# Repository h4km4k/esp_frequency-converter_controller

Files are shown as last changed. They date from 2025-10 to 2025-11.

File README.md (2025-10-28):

# esp_frequency-converter_controller
This is a repository to control a frequency converter (with 0-10V) via web interface.

The ESP8266 and ESP32-Websocket version is not latest, please do it by yourself if you need it (and if you did it, make a PR, thank you :)).

### CONTRIBUTIONS: 
#### #Thanks to Ole for designing and printing the 3D parts used in this project. Your contribution made the hardware setup possible!
#### #Many thanks also to Murph as the initiator.

## Parts used:
~~YB-ESP32-S3-ETH DevBoard with Ethernet+WiFi, 4MB Flash, 2xUSB, Antenna https://ebay.us/m/mVzUvF~~

1x WT32-ETH01 ESP32 WROOM LAN8720 Ethernet Arduino ESPEasy Tasmota Entwicklerboard https://ebay.us/m/NcotwB

1x PWM-Drehspannungsmodul, 0 % - 100 % PWM-Drehung auf 0 V-10 V Spannung https://ebay.us/m/Sh1sWy

2x 1-Kanal 3.3V Relais Modul mit Optokoppler (1Ch Relay Module High/Low Trigger) https://ebay.us/m/U08Ens

1x CH340G USB UART TTL Adapter 3,3V/5V für Arduino ESP8266 ESP32 Serial Converter https://ebay.us/m/q4AG8j

## The Circuit:

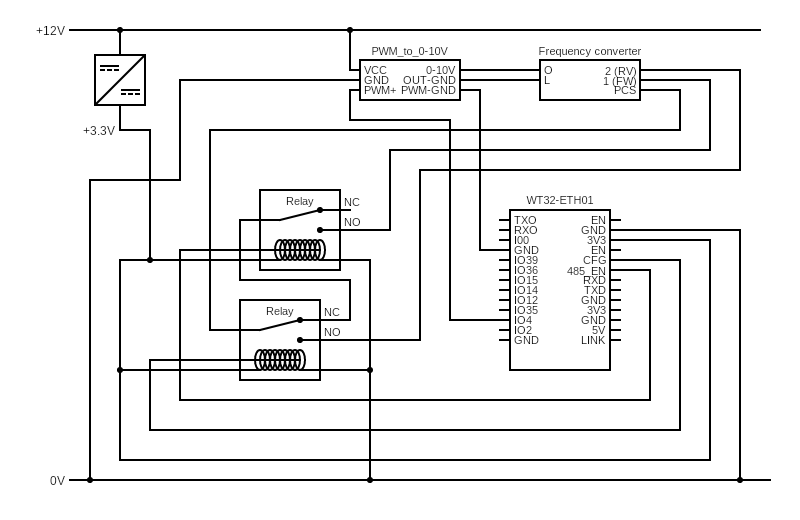
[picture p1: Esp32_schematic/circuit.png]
Circuit


## Favicon
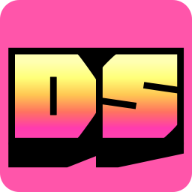
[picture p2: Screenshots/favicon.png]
Favicon


## Screenshots
<p align="left">
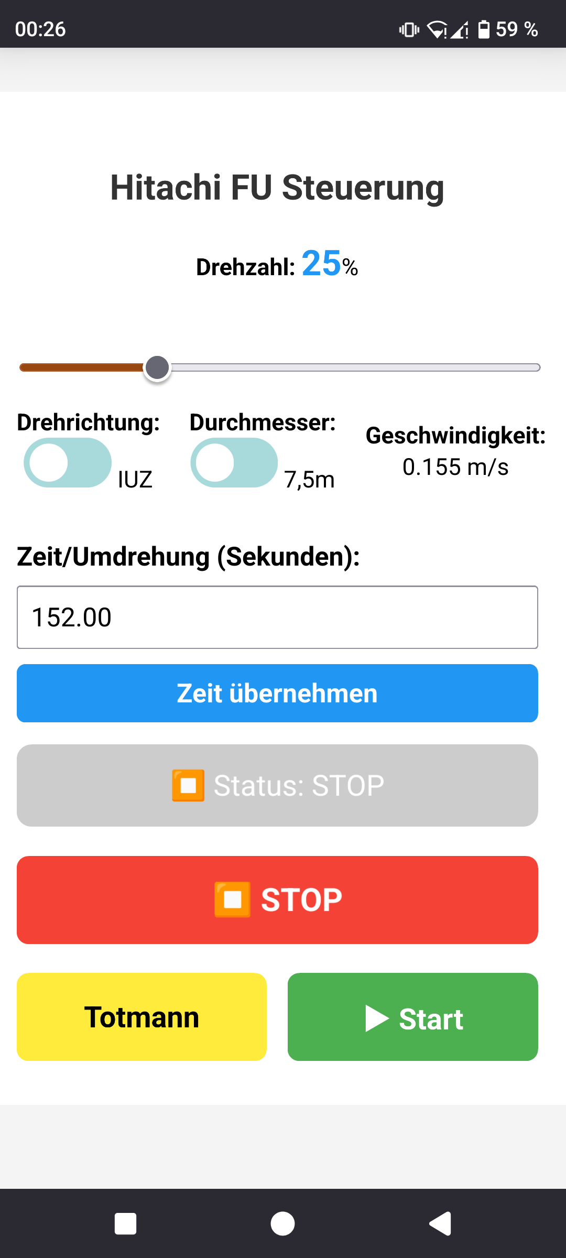
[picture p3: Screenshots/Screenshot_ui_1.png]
First Screenshot
  
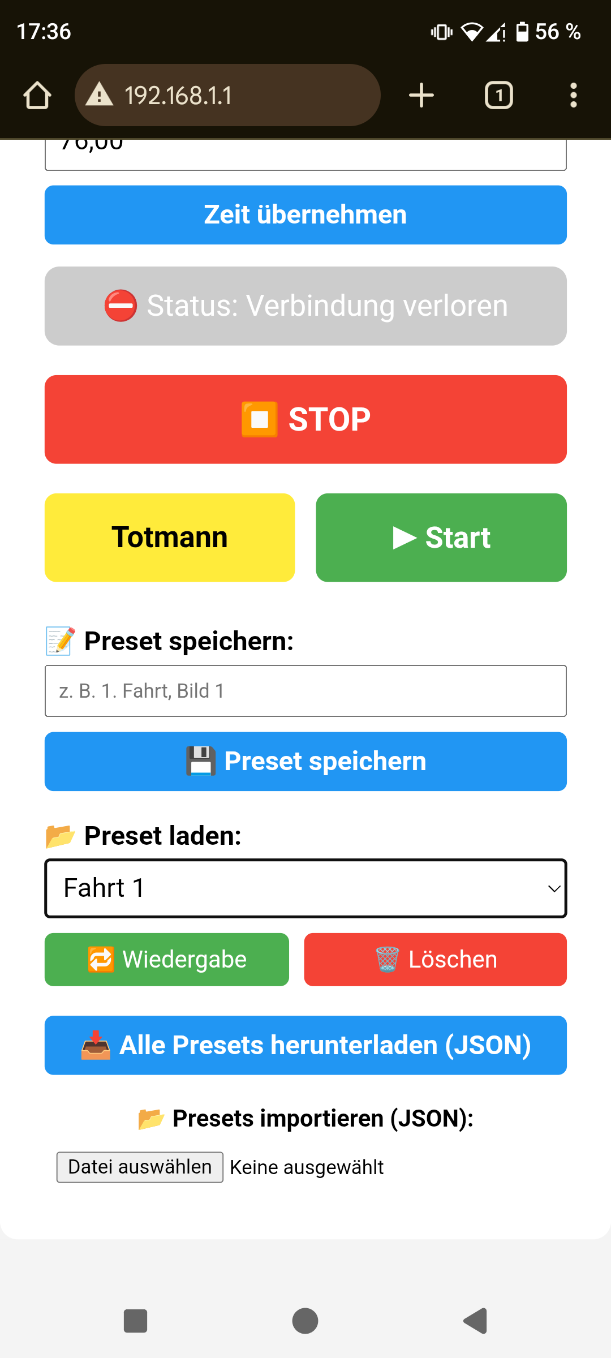
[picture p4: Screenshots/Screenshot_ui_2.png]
Second Screenshot
  
</p>

## 3D-Models
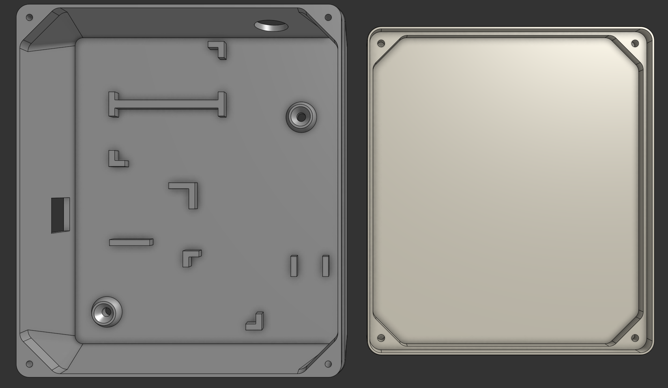
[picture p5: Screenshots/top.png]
Solid Top


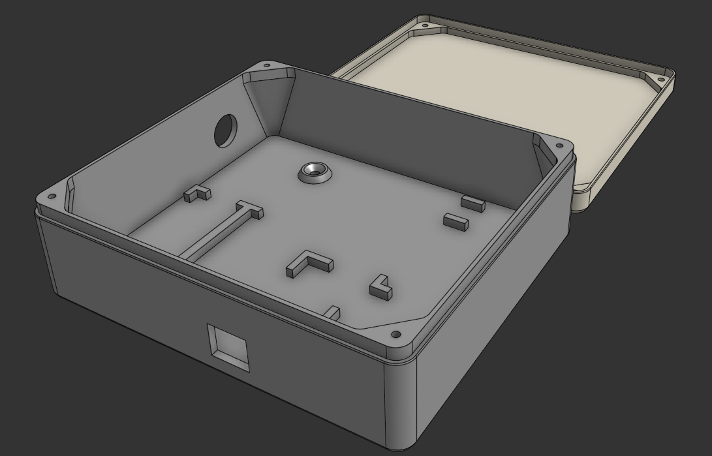
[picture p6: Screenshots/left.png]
Solid Left


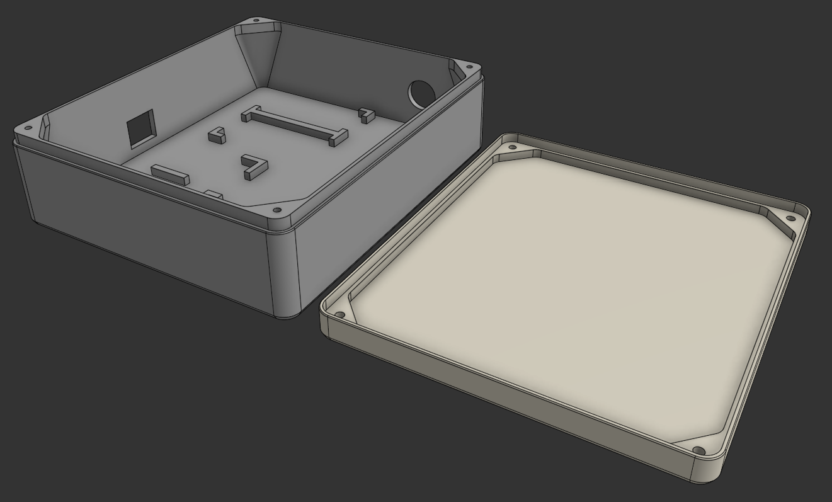
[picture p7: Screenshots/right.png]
Solid Right


## Assembled 

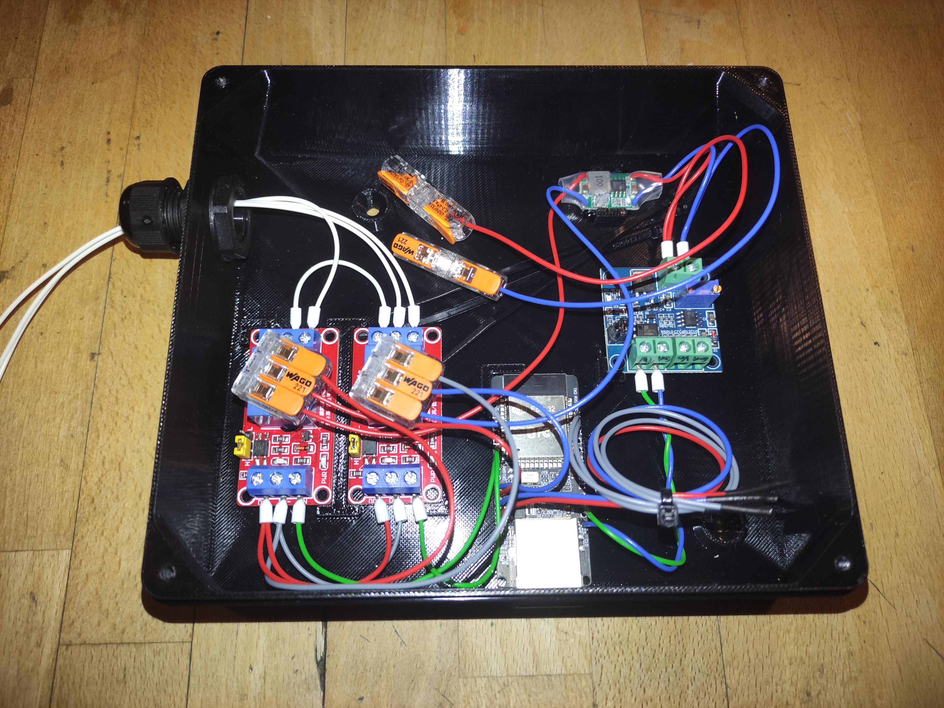
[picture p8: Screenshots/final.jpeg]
Assembly


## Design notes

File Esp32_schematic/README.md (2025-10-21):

To edit the schematic go to: <https://www.circuit-diagram.org/editor/> and load the *.cddx file into the editor.

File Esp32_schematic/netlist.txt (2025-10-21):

* Netlist created with www.circuit-diagram.org
* 
V1 0 3.3
'dcdcconverter primary:1 secondary:0 primary=DC secondary=DC
V2 2 0
'microcontroller #5:3 #1:4 #3:5 #0:6 #2:7 header=Frequency converter sz=6 p0=O p1=2 (RV) p2=L p3=1 (FW) p4= p5=PCS p6= p7= p8= p9= p10= p11= p12= p13= p14= p15= p16= p17= p18= p19= p20= p21= p22= p23= p24= p25= p26= p27= p28= p29= p30= p31= p32= p33= p34= p35= p36= p37= p38= p39=
'microcontroller #5:8 #1:6 #3:7 #2:2 #0:1 #4:9 header=PWM_to_0-10V sz=6 p0=VCC p1=0-10V p2=GND p3=OUT-GND p4=PWM+ p5=PWM-GND p6= p7= p8= p9= p10= p11= p12= p13= p14= p15= p16= p17= p18= p19= p20= p21= p22= p23= p24= p25= p26= p27= p28= p29= p30= p31= p32= p33= p34= p35= p36= p37= p38= p39=
'microcontroller #3:2 #5:0 #6:8 #20:9 #9:10 #11:11 header=WT32-ETH01 sz=30 p0=TXO p1=EN p2=RXO p3=GND p4=I00 p5=3V3 p6=GND p7=EN p8=IO39 p9=CFG p10=IO36 p11=485_EN p12=IO15 p13=RXD p14=IO14 p15=TXD p16=IO12 p17=GND p18=IO35 p19=3V3 p20=IO4 p21=GND p22=IO2 p23=5V p24=GND p25=LINK p26= p27= p28= p29= p30= p31= p32= p33= p34= p35= p36= p37= p38= p39=
'Relay 3:3 5:4 4:12 2:2 1:0
'Relay 5:5 3:12 4:13 2:2 1:0
V3 1 12

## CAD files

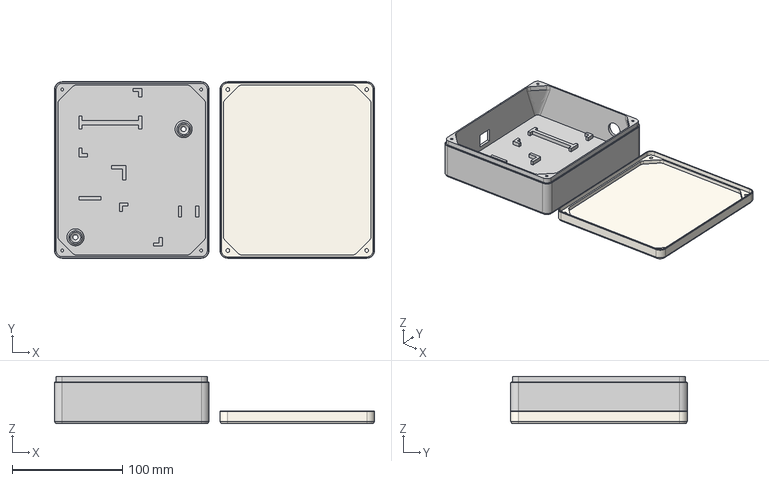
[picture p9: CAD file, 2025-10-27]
3d-files/DrehS_Frequenz_Gehause.step
290.0 x 160.0 x 43.0 mm

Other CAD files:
3d-files/DrehS_Frequenz_Gehause.stl

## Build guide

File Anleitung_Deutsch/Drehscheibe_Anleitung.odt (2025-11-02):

### Quickstart:

1. Vorbereitung:
Schalten Sie zunächst die mobilen Daten Ihres Endgeräts aus.

2. Verbindung herstellen:
Scannen Sie anschließend den WLAN-QR-Code.
Sobald die Verbindung mit „ESP-FU-Steuerung“ hergestellt ist, scannen Sie den LINK-QR-Code, um das User-Interface zu öffnen.

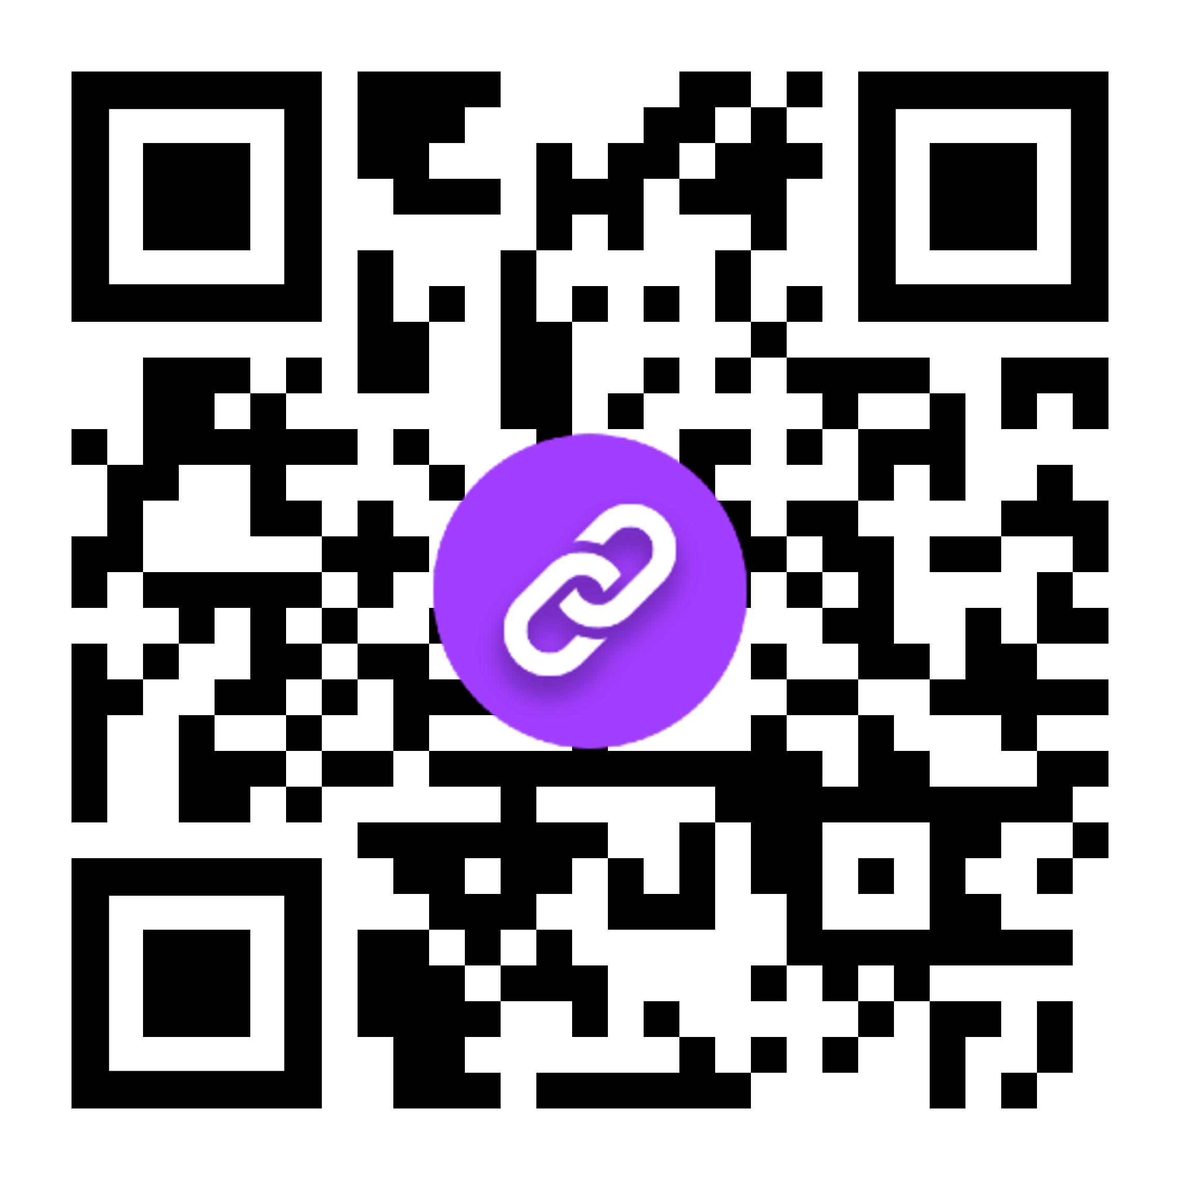
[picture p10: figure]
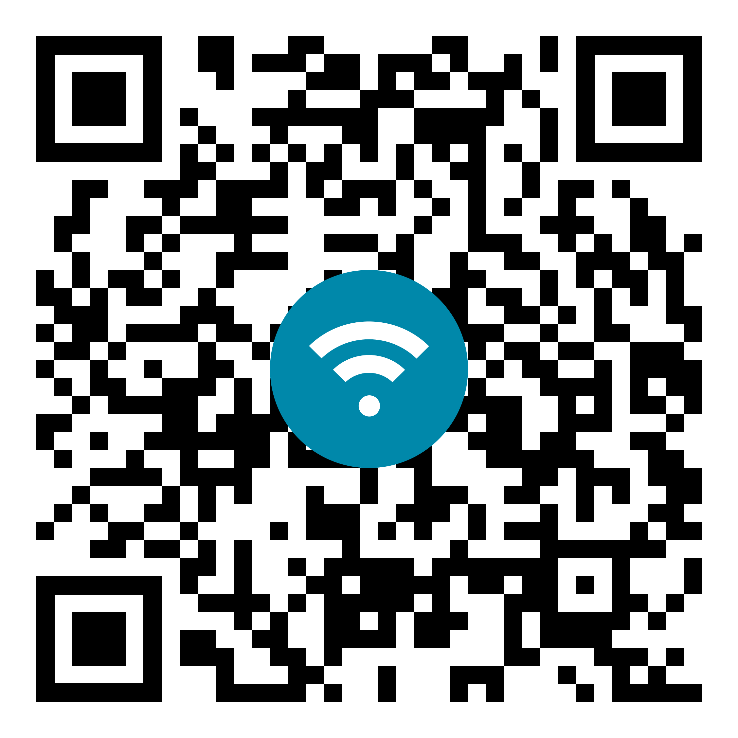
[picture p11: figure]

3. Bedienung:

1. Wählen Sie die gewünschte Drehrichtung und Geschwindigkeit (über den Slider oder per Zeiteingabe).

2. Drücken und halten Sie die „Totmensch“-Taste.

3. Zum Starten: Start-Taste drücken.

4. Zum Stoppen: Stop-Taste drücken.

Tipps&Tricks:

- Für vollen Funktionsumfang den Chrome Browser nutzen.

### Niemals Start oder Wiedergabe drücken ohne Totmensch.

### Wenn Etwas komisch ist in die Browser Adressleiste gehen und Seite neu laden.

## Erweiterte Funktionen

### LAN oder WLAN

LAN-Modus:
Wenn Sie das Gerät im LAN-Only-Modus betreiben möchten, schließen Sie Ihr eingeschaltetes Endgerät an den RJ45-Port an. Schalten Sie anschließend den Hauptschalter des Schaltschrankes ein.

WLAN-Modus:
Wird kein eingeschaltetes Gerät am LAN-Port erkannt, startet die Steuerung automatisch einen WLAN-Zugangspunkt.

Tipps & Tricks:

- Modus kann nur durch stromlos schalten geändert werden.

### Presets

Fahrt speichern:
Um eine gerade durchgeführte Fahrt zu speichern – inklusive aller Geschwindigkeitsänderungen (über Slider anpassen) und erneutes Starten – geben Sie einen Namen ein und drücken Sie auf „Preset speichern“.

Einschränkung:
Eine Fahrt, die durch Loslassen des „Totmensch“-Buttons beendet wurde, gilt nicht als gültige Fahrt und kann daher nicht gespeichert werden.

Tipps & Tricks:

- Presets funktionieren nur richtig, wenn der Motor keinen Schlupf hat.
- Presets wurden getestet, befinden sich aber noch in der BETA-Phase.
- Der Totmensch muss auch bei der Wiedergabe gehalten werden.

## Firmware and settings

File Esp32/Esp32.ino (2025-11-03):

#include <ETH.h>
#include <WiFi.h>
#include <WebServer.h>
#include <ArduinoOTA.h>
#include "DhcpServerLAN.h"
#include "esp_wifi.h"
#include "webinterface.h"
#include "favicon.h"
#include "manifest.h"

DhcpServerLAN dhcp;

WebServer server(80);

const char sw_js[] PROGMEM = R"(
self.addEventListener('install', (e) => {
  self.skipWaiting();
});
self.addEventListener('fetch', (e) => {
  e.respondWith(fetch(e.request));
});
)";

const char* ssid = "ESP-FU-Steuerung";
const char* password = "esp12345";

String currentDirection = "IUZ";
int dutyCycle = 0;
int currentPwm = 0;
int currentDuty = 0;
int targetPwm = 0;
bool startFreigegeben = false;
bool lanActive = false;
unsigned long lastTotmannSignal = 0;
const unsigned long totmannTimeout = 1000;

float scheibenDurchmesser = 7.5;



const int pwmPin = 4;
const int pwmFreq = 2900;
const int pwmResolution = 10;  // 10 Bit Auflösung (0-1023)
const int pwmRange = 1023;
const int minPWM = 80;  // Mindestwert, bei dem dein Motor zuverlässig anläuft (kannst du anpassen)

const int relay1Pin = 32;
const int relay2Pin = 33;


const int n = 11;
float fahrzeit[] = { 38.28, 38.25, 44.73, 51.84, 61.45, 73.56, 94.41, 126.24, 184.87, 531.15, 2000 };
int pwmProzent[] = { 100, 90, 80, 70, 60, 50, 40, 30, 20, 10, 1 };

unsigned long lastRampUpdate = 0;
const unsigned long rampStepDelay = 4;



int getPWMForFahrzeit(float zeit) {
  if (zeit <= fahrzeit[0]) return pwmProzent[0];
  if (zeit >= fahrzeit[n - 1]) return pwmProzent[n - 1];

  for (int i = 0; i < n - 1; i++) {
    if (zeit >= fahrzeit[i] && zeit <= fahrzeit[i + 1]) {
      float t1 = fahrzeit[i];
      float t2 = fahrzeit[i + 1];
      int p1 = pwmProzent[i];
      int p2 = pwmProzent[i + 1];

      float ratio = (zeit - t1) / (t2 - t1);
      int pwm = p1 + ratio * (p2 - p1);

      return pwm;
    }
  }
  return pwmProzent[n - 1];
}

void handleSet() {
  if (server.hasArg("duty")) {
    int val = server.arg("duty").toInt();
    if (val >= 0 && val <= 100) {
      if (val <= 0) {
        dutyCycle = 0;
      } else {
        dutyCycle = minPWM + (int)((val - 1) / 99.0 * (1023 - minPWM));
      }
      currentDuty = val;
      server.send(200, "text/plain", "OK");
      return;
    }
  }
  server.send(400, "text/plain", "Bad Request");
}

void handleTotmann() {
  lastTotmannSignal = millis();
  server.send(200, "text/plain", "Totmann OK");
}

void handleStart() {

  bool recentTotmann = (millis() - lastTotmannSignal) < totmannTimeout;

  if (!recentTotmann) {
    server.send(400, "text/plain", "Start verweigert: Totmensch nicht aktiv");
    return;
  }

  if (dutyCycle <= 0) {
    server.send(400, "text/plain", "Start verweigert: dutyCycle=0");
    return;
  }

  startFreigegeben = true;
  targetPwm = dutyCycle;
  server.send(200, "text/plain", "Start OK");
}

void handleStop() {
  targetPwm = 0;
  startFreigegeben = false;
  server.send(200, "text/plain", "Stop OK");
}


void handleStatus() {
  bool recentTotmann = (millis() - lastTotmannSignal) < totmannTimeout;

  String status;
  if (recentTotmann && startFreigegeben) {
    status = "aktiv";
  } else if (recentTotmann && !startFreigegeben) {
    status = "warte";
  } else {
    status = "stop";
  }

  String dir = currentDirection;
  int duty = currentDuty;
  String json = "{\"status\":\"" + status + "\",\"direction\":\"" + dir + "\",\"duty\":" + String(duty) + "}";

  server.send(200, "application/json", json);
}


void handleGetDuty() {
  int dutyPercent = map(dutyCycle, 0, pwmRange, 0, 100);
  server.send(200, "text/plain", String(dutyPercent));
}

void handleGetPwm() {
  if (server.hasArg("time")) {
    float zeit = server.arg("time").toFloat();
    int pwm = getPWMForFahrzeit(zeit);
    server.send(200, "text/plain", String(pwm));
  } else {
    server.send(400, "text/plain", "Missing 'time' parameter");
  }
}

void handleSetDiameter() {
  if (server.hasArg("d")) {
    String val = server.arg("d");
    if (val == "7.5" || val == "8.5") {
      scheibenDurchmesser = val.toFloat();
      server.send(200, "text/plain", "OK");
      return;
    }
  }
  server.send(400, "text/plain", "Bad Request");
}


void setRichtungStop() {
  digitalWrite(relay1Pin, LOW);
  digitalWrite(relay2Pin, LOW);
}


void handleRichtung() {
  if (server.hasArg("dir")) {
    String dir = server.arg("dir");

    if (dir == "stop") {
      digitalWrite(relay1Pin, LOW);
      digitalWrite(relay2Pin, LOW);
      currentDirection = "STOP";
      server.send(200, "text/plain", "Richtung: STOP");
      return;
    }

    if (dir == "iuz") {
      digitalWrite(relay1Pin, HIGH);
      digitalWrite(relay2Pin, LOW);
      currentDirection = "IUZ";
      server.send(200, "text/plain", "Richtung: Im Uhrzeigersinn");
      return;
    }

    if (dir == "guz") {
      digitalWrite(relay1Pin, LOW);
      digitalWrite(relay2Pin, HIGH);
      currentDirection = "GUZ";
      server.send(200, "text/plain", "Richtung: Gegen Uhrzeigersinn");
      return;
    }

    // Falscher Parameterwert
    server.send(400, "text/plain", "Ungueltiger Wert fuer 'dir'");
    return;
  }

  // 'dir' fehlt komplett
  server.send(400, "text/plain", "Fehlender Parameter 'dir'");
}



//////////////////////////////////SETUP/////////////////////////////////////
void setup() {
  // Serial.begin(115200);

  IPAddress LanIP(192, 168, 0, 1);
  IPAddress WlanIP(192, 168, 1, 1);
  IPAddress subnet(255, 255, 255, 0);


  ETH.begin();
  ETH.config(LanIP, LanIP, subnet);
  delay(10000);

  if (ETH.linkUp()) {

    // Serial.print("LAN IP: ");
    // Serial.println(LanIP);

    lanActive = true;

    dhcp.begin(LanIP);
    dhcp.setPoolRange(200, 254);
    dhcp.setLeaseTime(3600);

    WiFi.mode(WIFI_OFF);
  } else {
    ETH.end();
    WiFi.mode(WIFI_AP);
    WiFi.softAPConfig(WlanIP, WlanIP, subnet);

    wifi_country_t myCountry = {
      .cc = "DE",
      .schan = 1,
      .nchan = 13,
      .policy = WIFI_COUNTRY_POLICY_MANUAL
    };
    esp_wifi_set_country(&myCountry);
    esp_wifi_set_bandwidth(WIFI_IF_AP, WIFI_BW_HT20);

    WiFi.softAP(ssid, password);

    // Serial.print("WLAN IP: ");
    // Serial.println(WiFi.softAPIP());
  }

  ledcAttach(pwmPin, pwmFreq, pwmResolution);
  ledcWrite(pwmPin, 0);

  pinMode(relay1Pin, OUTPUT);
  pinMode(relay2Pin, OUTPUT);
  setRichtungStop();


  server.on("/", []() {
    handleRoot(server);
  });

  server.on("/deadman", HTTP_POST, handleTotmann);
  server.on("/set", HTTP_POST, handleSet);
  server.on("/start", HTTP_POST, handleStart);
  server.on("/stop", HTTP_POST, handleStop);
  server.on("/setDiameter", HTTP_POST, handleSetDiameter);
  server.on("/direction", HTTP_POST, handleRichtung);
  server.on("/status", HTTP_GET, handleStatus);
  server.on("/getDuty", HTTP_GET, handleGetDuty);
  server.on("/getPWMforTime", HTTP_GET, handleGetPwm);

  server.on("/favicon.png", []() {
    server.send_P(200, "image/png", (const char*)favicon_png, favicon_png_len);
  });
  server.on("/manifest.webmanifest", []() {
    server.send_P(200, "application/manifest+json", manifest_json);
  });

  server.begin();
  ArduinoOTA.setHostname("WT32-ETH01-OTA");
  ArduinoOTA.setPassword("8fQ8Zvg8qPkN");
  ArduinoOTA.begin();

  lastTotmannSignal = millis();
}

//////////////////////////////////LOOP/////////////////////////////////////
void loop() {
  if (lanActive) {
    dhcp.loop();
  }

  server.handleClient();

  ArduinoOTA.handle();

  unsigned long now = millis();
  if (currentPwm != targetPwm && (now - lastRampUpdate >= rampStepDelay)) {
    if (currentPwm < targetPwm) currentPwm++;
    else if (currentPwm > targetPwm) currentPwm--;

    if (currentPwm < 0) currentPwm = 0;
    if (currentPwm > pwmRange) currentPwm = pwmRange;

    ledcWrite(pwmPin, currentPwm);
    lastRampUpdate = now;
  }

  if ((millis() - lastTotmannSignal) > totmannTimeout && startFreigegeben) {
    startFreigegeben = false;
    targetPwm = 0;
    currentPwm = 0;
    ledcWrite(pwmPin, 0);
    setRichtungStop();
  }
}

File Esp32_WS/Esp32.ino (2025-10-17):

#include <WiFi.h>

#include <AsyncTCP.h>
#include <ESPAsyncWebServer.h>

#include "webinterface.h"

// #include <WiFiUdp.h>
// WiFiUDP udp;
// const unsigned int udpPort = 4210;

AsyncWebServer server(80);

// AsyncWebSocket ws("/ws");  // Endpunkt: ws://<ESP-IP>/ws

// unsigned long lastAlive = 0;  // optional separat tracken

const char *ssid = "ESP-FU-Steuerung";
const char *password = "esp12345";

String currentDirection = "IUZ";  // oder dein Default, z. B. "IUZ" / "GUZ"
int dutyCycle = 0;
int currentPwm = 0;
int currentDuty = 0;  // Startwert 0 oder was du willst
int targetPwm = 0;
bool startFreigegeben = false;
unsigned long lastTotmannSignal = 0;
const unsigned long totmannTimeout = 1000;  // Sicherheitsrelevant, 400ms sinnvoller Kompromiss

float scheibenDurchmesser = 7.5;

const int pwmPin = 5;  // GPIO5 (entspricht D5 auf ESP8266)
const int pwmChannel = 0;
const int pwmFreq = 2900;
const int pwmResolution = 10;  // 10 Bit Auflösung (0-1023)
const int pwmRange = 1023;

const int relay1Pin = 18;  // GPIO für Relais 1
const int relay2Pin = 19;  // GPIO für Relais 2


const int n = 11;
float fahrzeit[] = { 38.28, 38.25, 44.73, 51.84, 61.45, 73.56, 94.41, 126.24, 184.87, 531.15, 3000 };
int pwmProzent[] = { 100, 90, 80, 70, 60, 50, 40, 30, 20, 10, 1 };

unsigned long lastRampUpdate = 0;
const unsigned long rampStepDelay = 2;

float getPWMForFahrzeit(float zeit) {
  if (zeit <= fahrzeit[0]) return pwmProzent[0];
  if (zeit >= fahrzeit[n - 1]) return pwmProzent[n - 1];

  for (int i = 0; i < n - 1; i++) {
    float t1 = fahrzeit[i];
    float t2 = fahrzeit[i + 1];

    if (zeit >= t1 && zeit <= t2) {
      float p1 = pwmProzent[i];
      float p2 = pwmProzent[i + 1];
      float ratio = (zeit - t1) / (t2 - t1);
      float pwm = p1 + ratio * (p2 - p1);
      return pwm;
    }
  }

  return pwmProzent[n - 1];
}


// void onWsEvent(AsyncWebSocket *server, AsyncWebSocketClient *client,
//                AwsEventType type, void *arg, uint8_t *data, size_t len) {
//   if (type == WS_EVT_CONNECT) {
//     Serial.printf("Totmann WebSocket verbunden (Client #%u)\n", client->id());
//   } else if (type == WS_EVT_DISCONNECT) {
//     Serial.printf("Totmann WebSocket getrennt (Client #%u)\n", client->id());
//   } else if (type == WS_EVT_DATA) {
//     // jedes empfangene Paket gilt als "alive"
//     lastTotmannSignal = millis();
//     // Optional Debug:
//     // Serial.printf("WS Totmann-Signal von #%u, len=%u\n", client->id(), len);
//   }
// }


void handleSet(AsyncWebServerRequest *request) {
  if (request->hasParam("duty", true)) {  // true = auch POST-Body prüfen
    int val = request->getParam("duty", true)->value().toInt();

    if (val >= 0 && val <= 100) {
      dutyCycle = map(val, 0, 100, 0, pwmRange);
      request->send(200, "text/plain", "OK");
      return;
    }
  }

  request->send(400, "text/plain", "Bad Request");
}


void handleTotmann(AsyncWebServerRequest *request) {
  lastTotmannSignal = millis();
  request->send(200, "text/plain", "OK");
}


void handleStart(AsyncWebServerRequest *request) {
  bool recentTotmann = (millis() - lastTotmannSignal) < totmannTimeout;

  if (!recentTotmann) {
    Serial.println("Start verweigert: Totmann nicht aktiv.");
    request->send(403, "text/plain", "Totmann nicht aktiv");
    return;
  }

  if (dutyCycle <= 0) {
    Serial.println("Start verweigert: dutyCycle=0.");
    request->send(400, "text/plain", "DutyCycle=0");
    return;
  }

  startFreigegeben = true;
  targetPwm = dutyCycle;

  Serial.println("Start Befehl erhalten.");
  request->send(200, "text/plain", "Start OK");
}


void handleStop(AsyncWebServerRequest *request) {
  targetPwm = 0;
  startFreigegeben = false;
  Serial.println("Stop Befehl erhalten.");
  request->send(200, "text/plain", "Stop OK");
}


void setRichtungStop() {
  digitalWrite(relay1Pin, HIGH);
  digitalWrite(relay2Pin, HIGH);
  Serial.println("Richtung: STOP");
}


void handleStatus(AsyncWebServerRequest *request) {
  bool recentTotmann = (millis() - lastTotmannSignal) < totmannTimeout;

  String status;
  if (recentTotmann && startFreigegeben) {
    status = "aktiv";
  } else if (recentTotmann && !startFreigegeben) {
    status = "warte";
  } else {
    status = "stop";
  }

  String dir = currentDirection;
  int duty = currentDuty;

  String json = "{\"status\":\"" + status + "\",\"direction\":\"" + dir + "\",\"duty\":" + String(duty) + "}";

  request->send(200, "application/json", json);
}


void handleGetDuty(AsyncWebServerRequest *request) {
  int dutyPercent = map(dutyCycle, 0, pwmRange, 0, 100);
  request->send(200, "text/plain", String(dutyPercent));
}


void handleGetPwm(AsyncWebServerRequest *request) {
  if (request->hasParam("time")) {
    float zeit = request->getParam("time")->value().toFloat();
    float pwm = getPWMForFahrzeit(zeit);
    request->send(200, "text/plain", String(pwm, 2));
  } else {
    request->send(400, "text/plain", "Missing 'time' parameter");
  }
}


void handleSetDiameter(AsyncWebServerRequest *request) {
  if (request->hasParam("d", true)) {  // true = auch POST-Body prüfen
    String val = request->getParam("d", true)->value();
    if (val == "7.5" || val == "8.5") {
      scheibenDurchmesser = val.toFloat();
      request->send(200, "text/plain", "OK");
      return;
    }
  }
  request->send(400, "text/plain", "Bad Request");
}


void handleRichtung(AsyncWebServerRequest *request) {
  if (request->hasParam("dir", true)) {
    String dir = request->getParam("dir", true)->value();

    if (dir == "iuz") {
      digitalWrite(relay1Pin, HIGH);
      digitalWrite(relay2Pin, LOW);
      request->send(200, "text/plain", "Richtung: Im Uhrzeigersinn");
      return;
    }

    if (dir == "guz") {
      digitalWrite(relay1Pin, LOW);
      digitalWrite(relay2Pin, HIGH);
      request->send(200, "text/plain", "Richtung: Gegen Uhrzeigersinn");
      return;
    }

    if (dir == "stop") {
      digitalWrite(relay1Pin, HIGH);
      digitalWrite(relay2Pin, HIGH);
      request->send(200, "text/plain", "Richtung: Stop");
      return;
    }
  }

  request->send(400, "text/plain", "Bad Request");
}
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

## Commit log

2025-10-16 Added ESP32 support and in Presets in the ESP32 code. Currently not working.
2025-10-16 Deleted Esp32 in Esp8266 Folder.
2025-10-17 Added Websocket support and changed to async webserver (in ESP32_WS).
2025-10-17 The WOKE commit, finaly working esp32 version.
2025-10-21 Added schematic.
2025-10-21 Include circuit diagram in README
    Added circuit diagram to README.
2025-10-21 Replace SVG circuit image with PNG format
    Updated circuit image format in README.
2025-10-21 Add editing instructions to README.md
    Added instructions for editing the schematic file.
2025-10-23 Change circuit image width to 100%
    Updated circuit image to use full width.
2025-10-23 Swt correct Pins and updated schematics
    [Esp32.ino]
2025-10-27 A lot of Doku, added 3d files and some small code changes.
    [DrehS_Frequenz_Gehause.step, DrehS_Frequenz_Gehause.stl]
2025-10-27 Update README with ESP version note and thanks
    Added note about ESP8266 and ESP32-Websocket version.
2025-10-27 Revise ESP8266/ESP32-Websocket version note
    Updated note on ESP8266 and ESP32-Websocket version to encourage PRs.
2025-11-02 Some bug fixes, added minpwm!
    [Esp32.ino]
